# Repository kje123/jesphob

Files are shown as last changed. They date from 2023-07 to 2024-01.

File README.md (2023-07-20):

# jesphob
A fork of the PhobGCC project, created for the JESNET Gamecube Controller

If you've stumbled upon this, congrats! You have found this earlier than intended. This project is currently in the prototyping phase, so I do not recommend using this until I have done an official release, and I cannot help you if weird issues pop up.

If you wanna ask me questions or get involved, you can find me on Discord. My username is .kje

Original PhobGCC project here: https://github.com/PhobGCC

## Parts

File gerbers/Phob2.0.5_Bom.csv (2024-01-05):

Comment | Designator | Footprint | LCSC
1k | R16,R18 | C_0402_1005Metric | C11702
USB_B_Micro | J8 | USB_Micro-B_Amphenol_10118194_Horizontal | C132563
47u | C1 | CP_EIA-3528-12_Kemet-T_Pad1.50x2.35mm_HandSolder | C136751
CUS10S30,H3F | D1,D5 | D_SOD-323 | C146335
Q_PMOS_GDS | Q2 | SOT-23 | C15127
100n | C17,C19,C20,C22,C24,C25,C26,C27,C28,C29,C30,C31,C32 | C_0402_1005Metric | C1525
27p | C14,C15 | C_0402_1005Metric | C1557
10u | C16,C18 | C_0805_2012Metric | C15850
316 | R10,R19,R24,R25 | R_0402_1005Metric | C159037
0.047u | C3,C4,C5,C6,C7,C8 | C_0603_HandSoldering | C1622
RP2040 | U8 | RP2040-QFN-56 | C2040
Q_NMOS_GSD | Q1,Q3 | SOT-23 | C20917
100R | R11,R12 | R_0603_1608Metric_Pad0.98x0.95mm_HandSolder | C22775
2k | R3,R4,R5,R6 | R_0603_1608Metric_Pad0.98x0.95mm_HandSolder | C22975
27 | R20,R21 | C_0402_1005Metric | C25100
100k | R17 | R_0603_1608Metric_Pad0.98x0.95mm_HandSolder | C25803
10k | R13,R14,R15 | R_0603_1608Metric_Pad0.98x0.95mm_HandSolder | C25804
DRV5055A3xDBZxQ1 | U10,U11,U4,U9 | SOT-23 | C266128
USBLC6-2P6 | U12,U13 | SOT-666 | C2827693
BOOTSEL | S1 | SW_TS-1187A-B-A-B | C318884
180 | R1,R2,R7,R8,R9 | R_0402_1005Metric | C481962
Crystal_GND24 | Y1 | Crystal_SMD_3225-4Pin_3.2x2.5mm | C403945
1u | C21,C23 | C_0402_1005Metric | C52923
MCP3202 | U1,U3 | SOIC-8_3.9x4.9mm_P1.27mm | C56997
AMS1117-3.3 | U6 | SOT-223-3_TabPin2 | C6186
Fuse | F1 | Fuse_1206_3216Metric | C69680
M7C | D2 | D_SOD-123 | C8598
W25Q128JVS | U7 | SOIC-8_5.23x5.23mm_P1.27mm | C97521

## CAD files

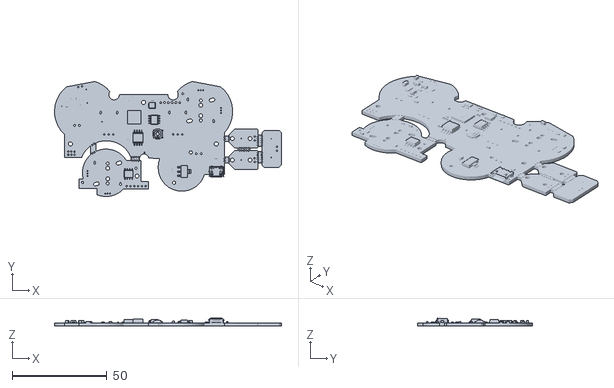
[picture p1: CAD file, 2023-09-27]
KiCAD/jesnet_test.stl
119.5 x 60.6 x 4.37

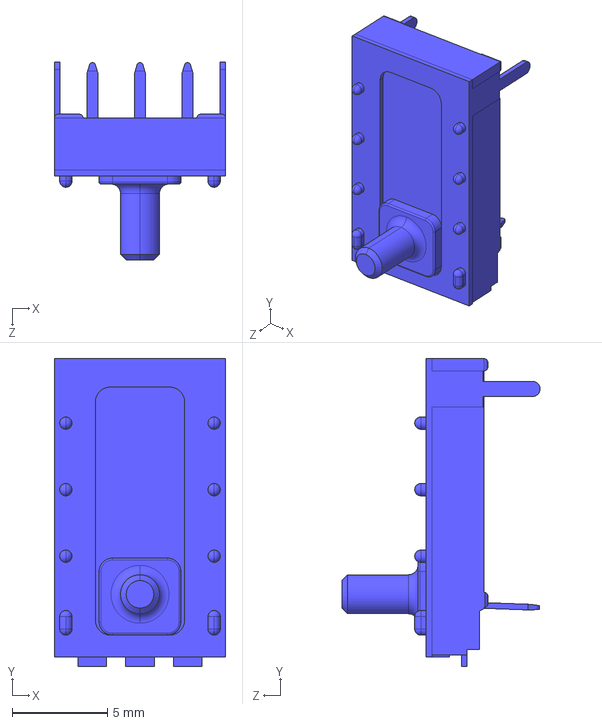
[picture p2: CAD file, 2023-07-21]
Phob PCB files/Models/XVJ09.STEP
9.00 x 16.2 x 10.4 mm

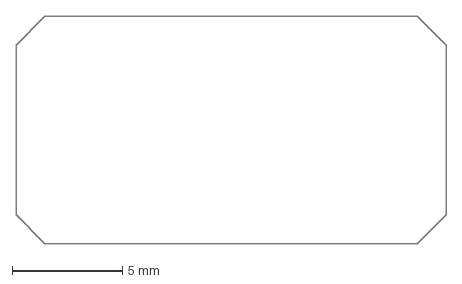
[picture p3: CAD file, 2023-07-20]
sketches/z.dxf
19.5 x 10.3 mm

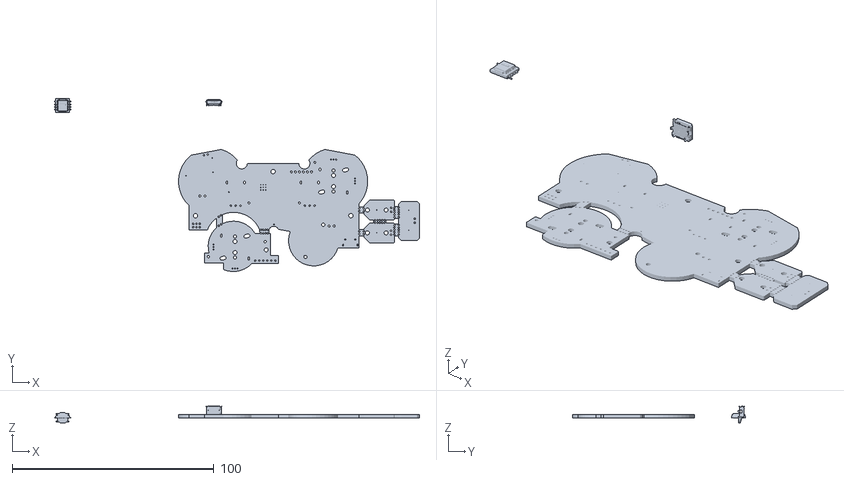
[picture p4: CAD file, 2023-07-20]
test.stl
181.1 x 85.8 x 8.38

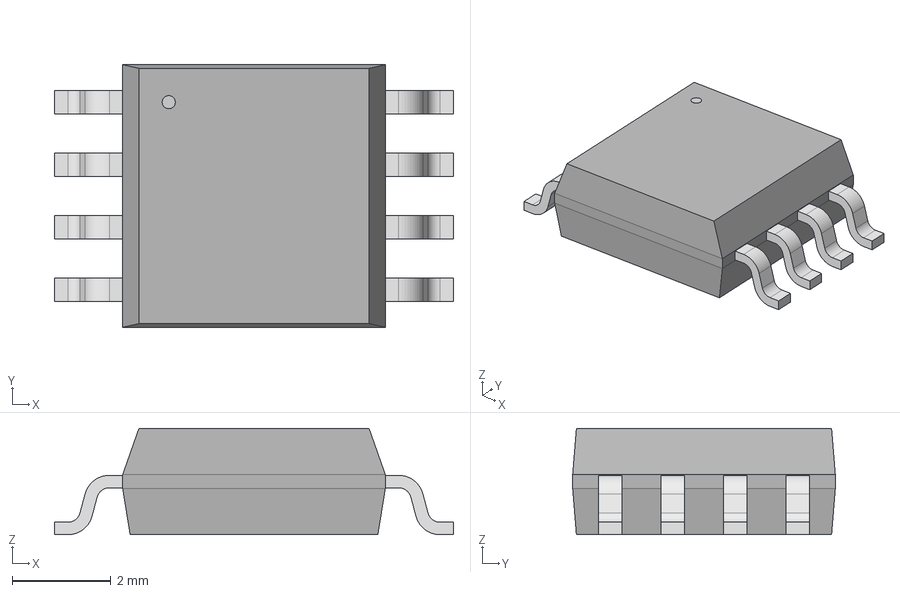
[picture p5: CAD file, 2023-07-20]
Phob PCB files/Models/SOIC_128JVSIQ_WIN.step
8.10 x 5.33 x 2.16 mm

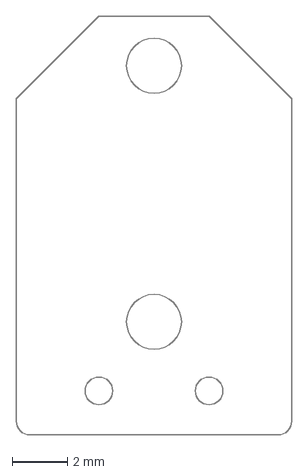
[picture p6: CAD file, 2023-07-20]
sketches/triggerpaddle.dxf
10.0 x 15.2 mm

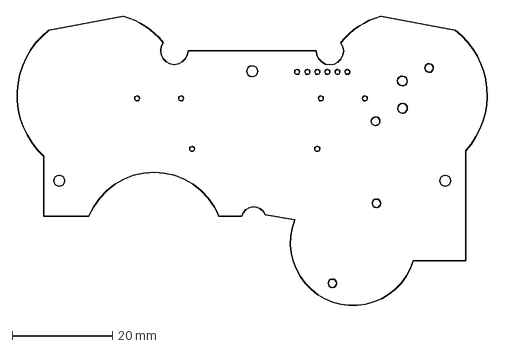
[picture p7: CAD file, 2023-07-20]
sketches/pcb.dxf
94.4 x 58.4 mm

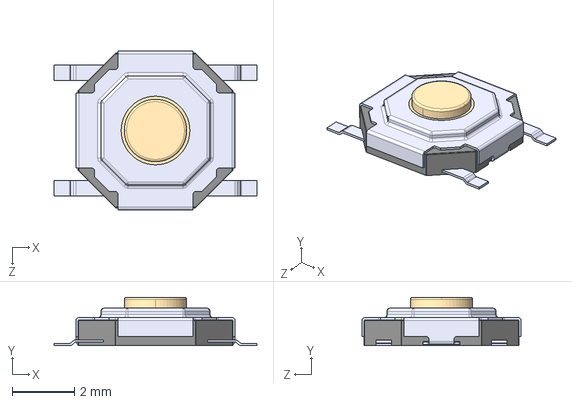
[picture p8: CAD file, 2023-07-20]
Phob PCB files/Models/TS-1187A-B-A-B--3DModel-STEP-56544.STEP
6.50 x 1.55 x 5.10 mm

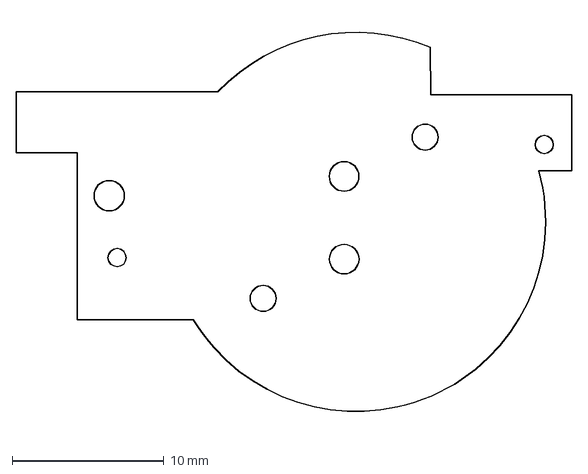
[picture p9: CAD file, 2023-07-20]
sketches/cstick.dxf
36.6 x 27.5 mm

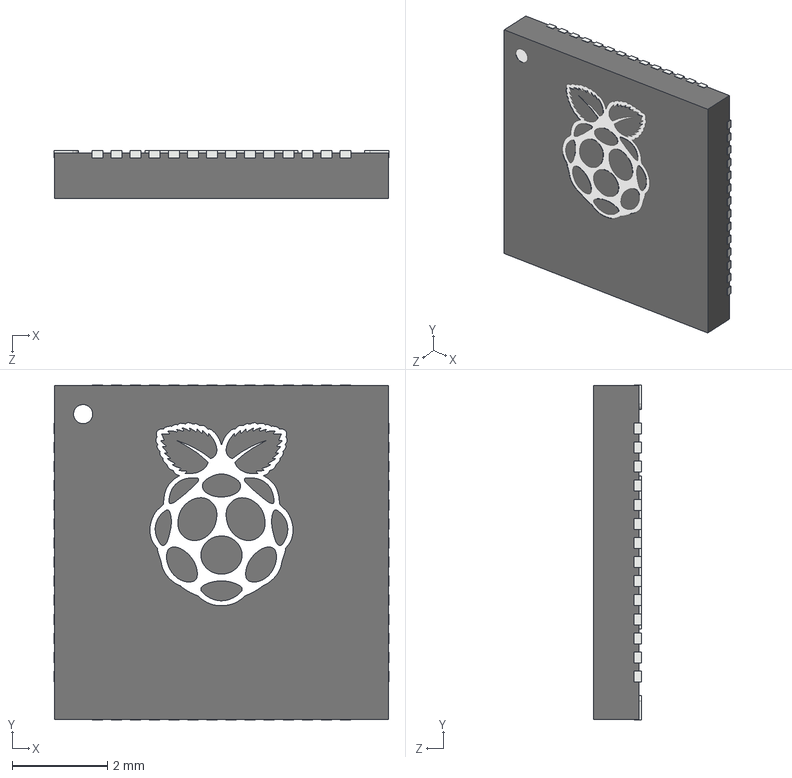
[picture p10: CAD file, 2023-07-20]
Phob PCB files/Models/RP2040_QFN_PACKAGE.STEP
7.02 x 7.02 x 1.00 mm

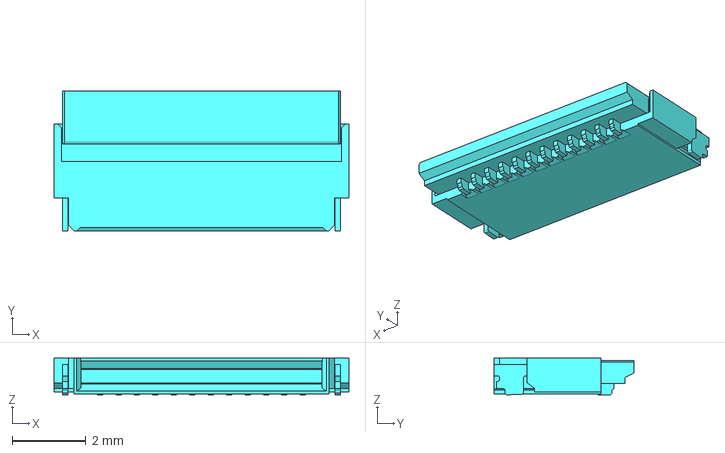
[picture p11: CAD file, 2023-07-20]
Phob PCB files/Models/FH34SRJ-12S-0.5SH.stp
8.00 x 3.80 x 1.00 mm

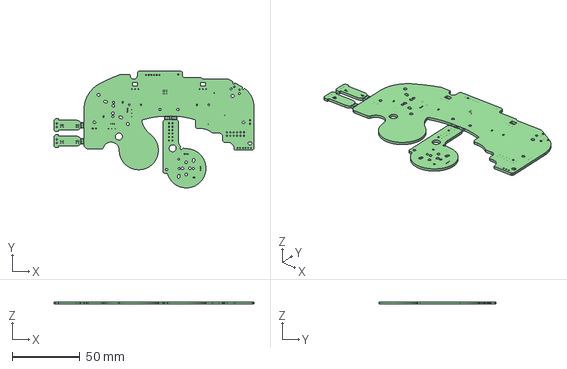
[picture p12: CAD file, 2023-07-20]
Phob PCB files/Models/PhobGCC_test.step
147.6 x 86.2 x 1.60 mm

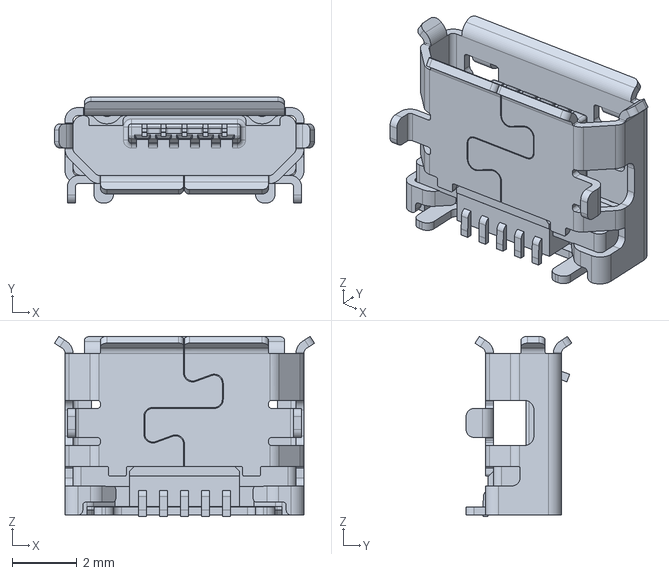
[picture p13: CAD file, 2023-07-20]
Phob PCB files/Models/10118194c.stp
8.05 x 3.27 x 5.58 mm

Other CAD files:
Phob PCB files/Models/10118194C.igs
Phob PCB files/Models/FH34SRJ-12S-0.5SH.igs

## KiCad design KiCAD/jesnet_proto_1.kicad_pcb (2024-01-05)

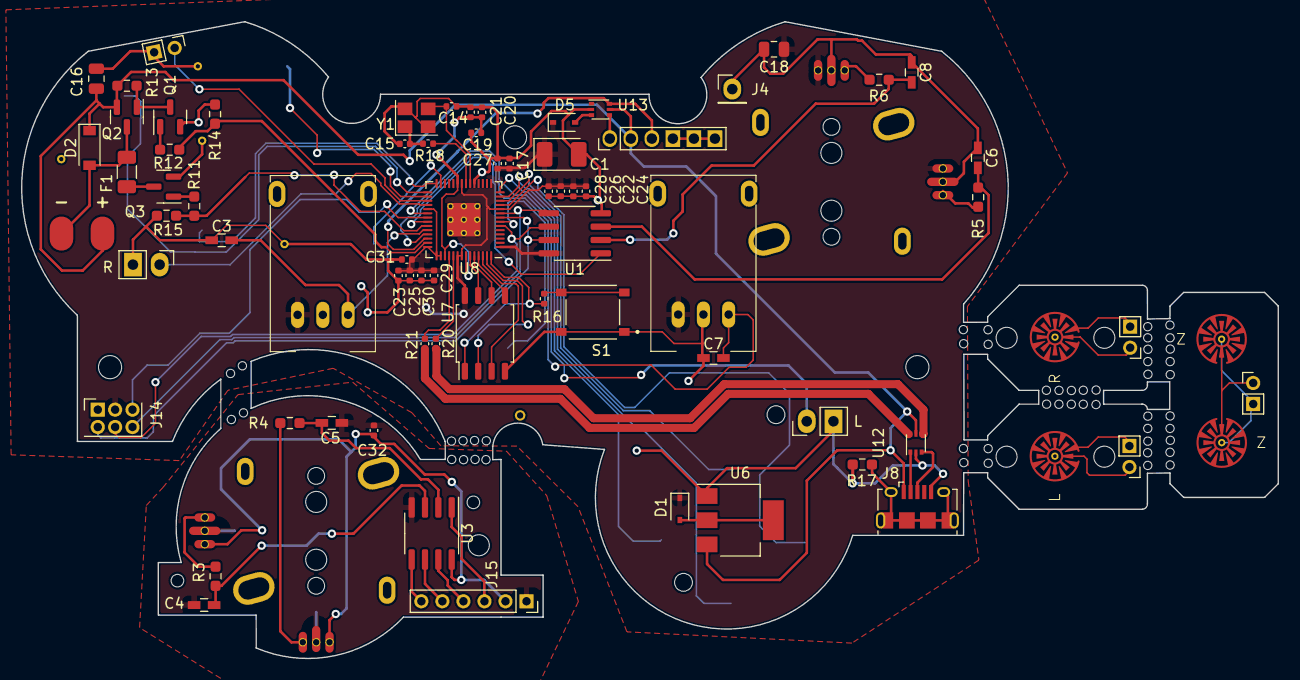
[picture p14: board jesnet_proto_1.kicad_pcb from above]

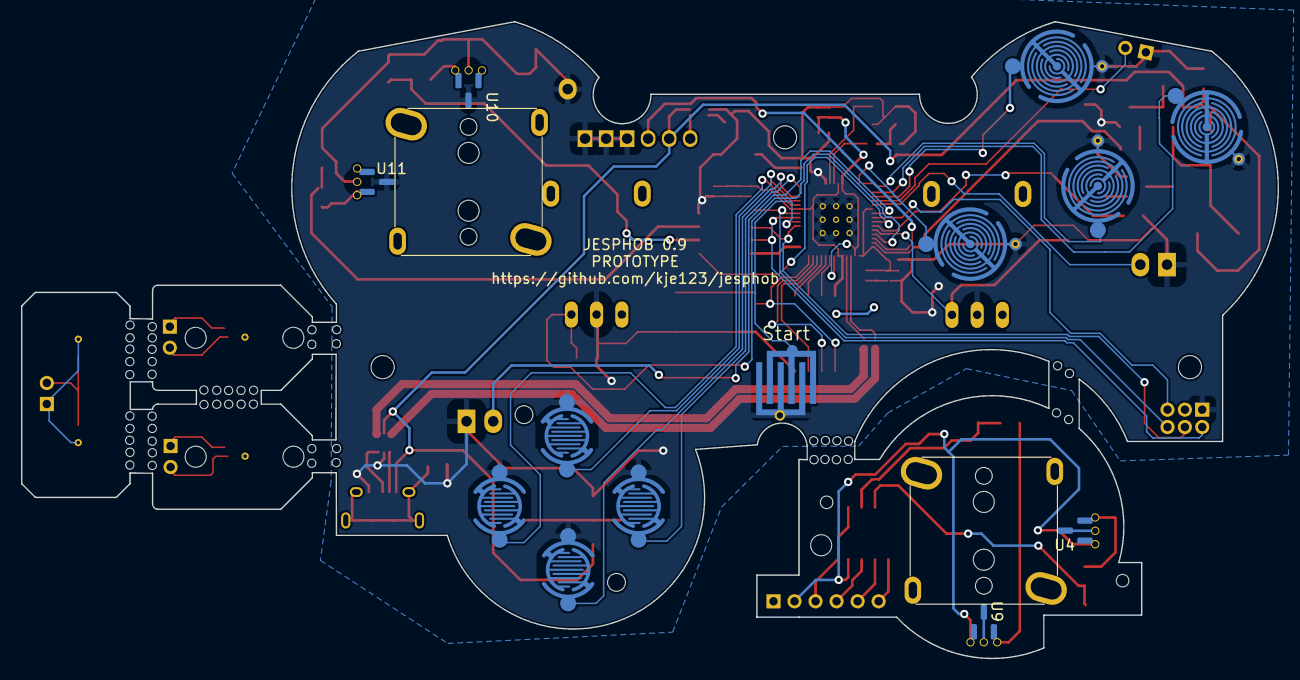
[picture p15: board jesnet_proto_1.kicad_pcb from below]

Board: 2 copper layers, 119.5 x 60.6 mm, 95 parts (15 on the bottom side), 65 nets.

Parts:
C1: 47u; CP_EIA-3528-12_Kemet-T_Pad1.50x2.35mm_HandSolder
C3, C4, C5, C6, C7, C8: 0.047u; C_0603_HandSoldering
C14, C15: 27p; C_0402_1005Metric
C16, C18: 10u; C_0805_2012Metric
C17, C19, C20, C22, C24, C25, C26, C27, C28, C29, C30, C31, C32: 100n; C_0402_1005Metric
C21, C23: 1u; C_0402_1005Metric
D1, D5: CUS10S30,H3F; D_SOD-323
D2: M7C; D_SOD-123
F1: Fuse; Fuse_1206_3216Metric
H5: 1.7mm; MountingHole_1.8mm
H9, H9#2, H9#3: 2.2mm; MountingHole_2.2mm
H10: 2mm; MountingHole_1.8mm
H10#2: 1.2mm; MountingHole_1.8mm
J1: Conn_01x06_Female; GCC_Header_Straight_1x06_Pitch2.00mm
J3, J3#2, J3#3, J3#4: Conn_01x02; PinHeader_1x02_P2.00mm_Horizontal
J4: Conn_01x01; PinHeader_1x01_P2.54mm_Vertical
J5: Rumble; rumble_pins
J8: USB_B_Micro; USB_Micro-B_Amphenol_10118194_Horizontal
J14, J15: Conn_01x06; PinSocket_1x06_P2.00mm_Vertical
Q1, Q3: Q_NMOS_GSD; SOT-23
Q2: Q_PMOS_GDS; SOT-23
R3, R4, R5, R6: 2k; R_0603_1608Metric_Pad0.98x0.95mm_HandSolder
R11, R12: 100R; R_0603_1608Metric_Pad0.98x0.95mm_HandSolder
R13, R14, R15: 10k; R_0603_1608Metric_Pad0.98x0.95mm_HandSolder
R16, R18: 1k; C_0402_1005Metric
R17: 100k; R_0603_1608Metric_Pad0.98x0.95mm_HandSolder
R20, R21: 27; C_0402_1005Metric
RV1, RV2: R_POT_MountingPin; GCC_Slider
S1: BOOTSEL; SW_TS-1187A-B-A-B
SW1: A; ABXY_Contact_Omron_Switch_Circley
SW2: L; Trigger_Contact
SW2#2, SW2#4: Z; Trigger_Contact
SW2#3: R; Trigger_Contact
SW2#5: B; ABXY_Contact_Omron_Switch_Circley
SW3: X; ABXY_Contact_Omron_Switch_Circley
SW4: Y; ABXY_Contact_Omron_Switch_Circley
SW5: Start; Start_Contact
SW6: L; Pin_Header_Straight_1x02_Pitch2.54mm
SW7: R; Pin_Header_Straight_1x02_Pitch2.54mm
SW9: Dleft; Dpad_Contact_TL3315NF_2_ZigZag
SW10: Dup; Dpad_Contact_TL3315NF_2_ZigZag
SW11: Dright; Dpad_Contact_TL3315NF_2_ZigZag
SW12: Ddown; Dpad_Contact_TL3315NF_2_ZigZag
U1, U3: MCP3202; SOIC-8_3.9x4.9mm_P1.27mm
U2: Stickbox_Assembly_Main; GCC_Stickbox_Hall_Only
U4, U9, U10, U11: DRV5055A3xDBZxQ1; SOT-23
U5: Stickbox_Assembly_CStick; GCC_Stickbox_Hall_Only
U6: AMS1117-3.3; SOT-223-3_TabPin2
U7: W25Q128JVS; SOIC-8_5.23x5.23mm_P1.27mm
U8: RP2040; RP2040-QFN-56
U12, U13: USBLC6-2P6; SOT-666
Y1: Crystal_GND24; Crystal_SMD_3225-4Pin_3.2x2.5mm

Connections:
+1V1: C19.1, C20.1, C21.1, U8.23 (DVDD), U8.45 (VREG_VOUT), U8.50 (DVDD)
+3V3: C1.1, C17.1, C18.1, C22.1, C23.1, C24.1, C25.1, C26.1, C27.1, C28.1, C29.1, C30.1, C31.1, D1.1 (K), D5.1 (K), J14.2, RV1.1 (V+), RV2.1 (V+), U1.8 (VDD/VREF), U2.1 (H1XV), U2.4 (H1YV), U7.8 (VCC), U8.1 (IOVDD), U8.10 (IOVDD), U8.22 (IOVDD), U8.33 (IOVDD), U8.42 (IOVDD), U8.43 (ADC_AVDD), U8.44 (VREG_IN), U8.48 (USB_VDD), U8.49 (IOVDD), U10.1 (VCC), U11.1 (VCC)
+5V: C16.1, D2.1 (K), J1.2, J5.1, J8.1 (VBUS), Q2.2 (S), R13.2, U6.3 (VI), U12.5 (VBUS), U13.5 (VBUS)
/A: SW1.1, U8.28 (GPIO17)
/B: SW2#5.1, U8.27 (GPIO16)
/Brake: R12.1, R14.2, U8.41 (GPIO29_ADC3)
/CLK: J14.4, U1.7 (CLK), U8.8 (GPIO6)
/CLK2: J15.4, U3.7 (CLK)
/CS1: U1.1 (~CS/SHDN), U8.36 (GPIO24)
/CS2: J14.3, U8.35 (GPIO23)
/CS2_2: J15.3, U3.1 (~CS/SHDN)
/C_x_filt: C5.1, R4.1, U3.2 (CH0)
/C_y_filt: C4.1, R3.1, U3.3 (CH1)
/Ddown: SW12.1, U8.13 (GPIO10)
/Din: J14.6, U1.5 (DIN), U8.9 (GPIO7)
/Din2: J15.6, U3.5 (DIN)
/Dleft: SW9.1, U8.11 (GPIO8)
/Dout: J14.5, U1.6 (DOUT), U8.6 (GPIO4)
/Dout2: J15.5, U3.6 (DOUT)
/Dright: SW11.1, U8.14 (GPIO11)
/Dup: SW10.1, U8.12 (GPIO9)
/GCC_3.3V: J1.1, U13.4 (I/O2)
/GCC_DATA: J1.3, U8.40 (GPIO28_ADC2), U13.6 (I/O1)
/GND_C: C4.2, C5.2, C32.2, J15.1, U3.4 (VSS), U4.3 (GND), U5.2 (H1XG), U5.5 (H1YG), U9.3 (GND)
/H1XS: R6.2, U2.3 (H1XS), U10.2 (OUT)
/H1YS: R5.2, U2.6 (H1YS), U11.2 (OUT)
/H2XS: R4.2, U5.3 (H1XS), U9.2 (OUT)
/H2YS: R3.2, U4.2 (OUT), U5.6 (H1YS)
/L: SW6.1, U8.34 (GPIO22)
/Lanalog: C7.1, RV1.3 (Signal), U8.39 (GPIO27_ADC1)
/QSPI_SCLK: U7.6 (CLK), U8.52 (QSPI_SCLK)
/QSPI_SD0: U7.5 (DI(IO0)), U8.53 (QSPI_SD0)
/QSPI_SD1: U7.2 (DO(IO1)), U8.55 (QSPI_SD1)
/QSPI_SD2: U7.3 (IO2), U8.54 (QSPI_SD2)
/QSPI_SD3: U7.7 (IO3), U8.51 (QSPI_SD3)
/QSPI_SS: R16.1, U7.1 (~CS), U8.56 (QSPI_SS)
/R: SW7.1, U8.32 (GPIO21)
/Ranalog: C3.1, RV2.3 (Signal), U8.38 (GPIO26_ADC0)
/Rumble: R11.1, R15.2, U8.37 (GPIO25)
/Start: SW5.1, U8.7 (GPIO5)
/Stick_x_filt: C8.1, R6.1, U1.2 (CH0)
/Stick_y_filt: C6.1, R5.1, U1.3 (CH1)
/USB_D+: R20.1, U12.4 (I/O2)
/USB_D+_Raw: J8.3 (D+), U12.3 (I/O2)
/USB_D-: R21.1, U12.6 (I/O1)
/USB_D-_Raw: J8.2 (D-), U12.1 (I/O1)
/X: SW3.1, U8.29 (GPIO18)
/XIN: C14.1, U8.20 (XIN), Y1.3
/XOUT: R18.1, U8.21 (XOUT)
/Y: SW4.1, U8.30 (GPIO19)
/Z: J3.2, U8.31 (GPIO20)
/~USB_BOOT: R16.2, S1.C, S1.D
GND: C1.2, C3.2, C6.2, C7.2, C8.2, C14.2, C15.2, C16.2, C17.2, C18.2, C19.2, C20.2, C21.2, C22.2, C23.2, C24.2, C25.2, C26.2, C27.2, C28.2, C29.2, C30.2, C31.2, J1.4, J1.5, J1.6, J3.1, J4.1, J8.5 (GND), J14.1, Q1.2 (S), Q3.2 (S), R14.1, R15.1, R17.2, RV1.2 (GND), RV2.2 (GND), S1.A, S1.B, SW1.2, SW2#5.2, SW3.2, SW4.2, SW5.2, SW6.2, SW7.2, SW9.2, SW10.2, SW11.2, SW12.2, U1.4 (VSS), U2.2 (H1XG), U2.5 (H1YG), U6.1 (GND), U7.4 (GND), U8.19 (TESTEN), U8.57 (GND), U10.3 (GND), U11.3 (GND), U12.2 (GND), U13.2 (GND), Y1.2, Y1.4
unnamed: C15.1, R18.2, Y1.1
unnamed: D1.2 (A), U6.2 (VO)
unnamed: D2.2 (A), F1.1, J5.2, Q2.3 (D)
unnamed: D5.2 (A), U13.3 (I/O2)
unnamed: F1.2, Q3.3 (D)
unnamed: J8.6 (Shield), R17.1
unnamed: Q1.1 (G), R12.2
unnamed: Q1.3 (D), Q2.1 (G), R13.1
unnamed: Q3.1 (G), R11.2
unnamed: R20.2, U8.47 (USB_DP)
unnamed: R21.2, U8.46 (USB_DM)
VCC: C32.1, J15.2, U3.8 (VDD/VREF), U4.1 (VCC), U5.1 (H1XV), U5.4 (H1YV), U9.1 (VCC)

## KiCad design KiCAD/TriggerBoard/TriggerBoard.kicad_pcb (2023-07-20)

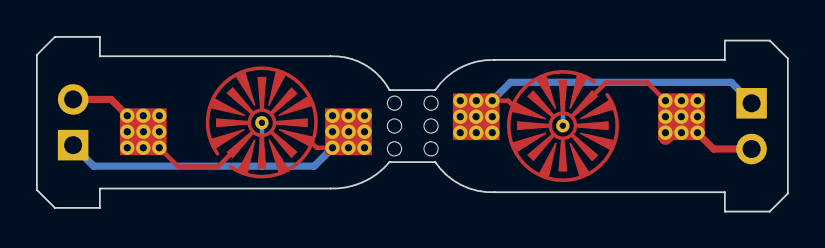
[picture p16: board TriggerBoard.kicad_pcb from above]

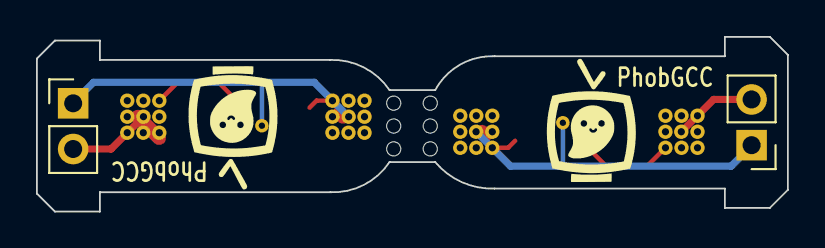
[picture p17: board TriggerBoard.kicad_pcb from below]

Board: 2 copper layers, 41.7 x 9.7 mm, 5 parts (2 on the bottom side), 4 nets.

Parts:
H2: MouseBiteRA; breakaway-mousebites-double
J1: L; Pin_Header_Straight_1x02_Pitch2.54mm
J2: R; Pin_Header_Straight_1x02_Pitch2.54mm
SW1: L; Trigger_Contact_Big
SW2: R; Trigger_Contact_Big

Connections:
unnamed: J1.1, SW1.1
unnamed: J1.2, SW1.2
unnamed: J2.1, SW2.1
unnamed: J2.2, SW2.2

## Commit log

2023-07-20 added prototype files
    [10118194C.igs, 10118194c.stp, FH34SRJ-12S-0.5SH.igs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]
2023-07-20 added 3d models to footprints, reversed polarity on trigger sliders
    [jesnet_proto_1.kicad_pcb]
2023-07-20 rerouted some traces, fixed 3d model of c0603
    [jesnet_proto_1.kicad_pcb, test.stl]
2023-07-21 added 3d models, adjusted stickbox positioning
    [XVJ09.STEP, jesnet_proto_1.kicad_pcb, jesnet_test.stl]
2023-09-27 final stickbox adjustments
    [jesnet_proto_1-B_Cu.gbl, jesnet_proto_1-B_Mask.gbs, jesnet_proto_1-B_Silkscreen.gbo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]
2024-01-05 prototype gerbers bom pos generated
    [Phob2.0.5_Bom.csv, jesnet_bom.csv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]
2024-01-05 deleted bad bom
    [jesnet_bom.csv]

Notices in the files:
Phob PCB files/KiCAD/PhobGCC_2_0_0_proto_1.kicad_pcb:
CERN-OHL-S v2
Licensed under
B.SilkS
